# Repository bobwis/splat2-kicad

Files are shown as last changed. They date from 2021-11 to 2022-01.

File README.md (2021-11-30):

# splat2-kicad

Copy freerouter.jar to %appdata%\kicad  (needs java installation etc, not covered here)
Copy route.py to %appdata%\kicad\scripting\plugins  (create dir if doesn't exist)
Tools->External Plugins->Refresh

Preferences->Preferences->Pcbnew->Action Plugins
Select plugin
Click Show button

Now the hammer icon should be on the toolbar

To use
Export DSN to default file (do not rename)
Click the hammer

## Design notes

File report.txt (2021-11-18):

Info: Processing component “J15:/63877BF5:Connector_PinHeader_2.54mm:PinHeader_2x04_P2.54mm_Vertical”.

Info: Processing component “C4:/5BF5E583:Capacitor_SMD:C_1210_3225Metric_Pad1.42x2.65mm_HandSolder”.

Info: Processing component “R3:/5C0A226D:Capacitor_SMD:C_1210_3225Metric_Pad1.42x2.65mm_HandSolder”.

Info: Processing component “C23:/5BE7E7BD:Capacitor_THT:CP_Radial_D5.0mm_P2.50mm”.

Info: Processing component “C20:/6318842A:Capacitor_THT:CP_Radial_D5.0mm_P2.50mm”.

Info: Processing component “C5:/6216B77B:Capacitor_THT:CP_Radial_D5.0mm_P2.50mm”.

Info: Processing component “C2:/64F25216:Capacitor_THT:CP_Radial_D5.0mm_P2.50mm”.

Info: Processing component “J5:/5BD26EDD:Connector_Coaxial:SMA_Amphenol_132134-11_Vertical”.

Info: Processing component “J11:/63186258:Connector_PinHeader_2.54mm:PinHeader_1x02_P2.54mm_Vertical”.

Info: Processing component “J14:/61992824:Connector_PinHeader_2.54mm:PinHeader_1x02_P2.54mm_Vertical”.

Info: Processing component “J10:/62DA21AF:Connector_PinHeader_2.54mm:PinHeader_1x03_P2.54mm_Vertical”.

Info: Processing component “J9:/630317BA:Connector_PinHeader_2.54mm:PinHeader_1x03_P2.54mm_Vertical”.

Info: Processing component “J13:/62D151F9:Connector_PinHeader_2.54mm:PinHeader_1x04_P2.54mm_Vertical”.

Info: Processing component “C6:/5BDE9061:Capacitor_SMD:C_0805_2012Metric_Pad1.15x1.40mm_HandSolder”.

Info: Processing component “J1:/618B991A:Connector_Samtec_HLE_THT:Samtec_HLE-136-02-xx-DV-TE_2x36_P2.54mm_Horizontal”.

Info: Processing component “J2:/61D28094:Connector_Samtec_HLE_THT:Samtec_HLE-136-02-xx-DV-TE_2x36_P2.54mm_Horizontal”.

Info: Processing component “D1:/5BE6C923:Diode_SMD:D_SMA_Handsoldering”.

Info: Processing component “FB1:/61CAF7CB:Inductor_SMD:L_0805_2012Metric”.

Info: Processing component “FB2:/5BDA7EC0:Inductor_SMD:L_0805_2012Metric”.

Info: Processing component “FB3:/5BE721A5:Inductor_SMD:L_0805_2012Metric”.

Info: Processing component “FB4:/63597DFE:Inductor_SMD:L_0805_2012Metric”.

Info: Processing component “L1:/5BDE60A7:Inductor_SMD:L_1210_3225Metric_Pad1.42x2.65mm_HandSolder”.

Info: Processing component “L2:/5BDE8EA2:Inductor_SMD:L_1210_3225Metric_Pad1.42x2.65mm_HandSolder”.

Info: Processing component “D7:/5BF5D97C:LED_SMD:LED_PLCC-2”.

Info: Processing component “D2:/664D24EE:LED_SMD:LED_PLCC-2”.

Info: Processing component “C14:/63187970:Capacitor_SMD:C_0805_2012Metric”.

Info: Processing component “U3:/618C0BE9:SOIC127P790X216-8N”.

Info: Processing component “U4:/618C0AC4:SOIC127P790X216-8N”.

Info: Processing component “U6:/61E29CE2:XCVR_E180-ZG120A”.

Info: Processing component “C25:/631889B9:Capacitor_SMD:CP_Elec_8x10”.

Info: Processing component “C15:/5C4010D5:Capacitor_SMD:CP_Elec_8x10”.

Info: Processing component “C11:/635D681B:Capacitor_SMD:CP_Elec_8x10”.

Info: Processing component “C22:/635D69B8:Capacitor_SMD:C_0402_1005Metric”.

Info: Processing component “C18:/63188597:Capacitor_SMD:C_0402_1005Metric”.

Info: Processing component “C3:/5BDACAE4:Capacitor_SMD:C_0402_1005Metric”.

Info: Processing component “C26:/61B65493:Capacitor_SMD:C_0603_1608Metric”.

Info: Processing component “C16:/63187C64:Capacitor_SMD:C_0805_2012Metric”.

Info: Processing component “D8:/66EE6485:LED_SMD:LED_PLCC-2”.

Info: Processing component “C17:/63187D42:Capacitor_SMD:C_0805_2012Metric”.

Info: Processing component “C19:/63187E12:Capacitor_SMD:C_0805_2012Metric”.

Info: Processing component “C10:/6207CE49:Capacitor_SMD:C_0805_2012Metric”.

Info: Processing component “C21:/63187EDE:Capacitor_SMD:C_0805_2012Metric”.

Info: Processing component “C1:/65067AB3:Capacitor_SMD:C_0805_2012Metric”.

Info: Processing component “C8:/5C39DBA4:Capacitor_SMD:C_0805_2012Metric”.

Info: Processing component “C13:/5CCB7C4C:Capacitor_SMD:C_0805_2012Metric_Pad1.15x1.40mm_HandSolder”.

Info: Processing component “C12:/629B2DE5:Capacitor_SMD:C_0805_2012Metric_Pad1.15x1.40mm_HandSolder”.

Info: Processing component “C24:/62741EFC:Capacitor_SMD:C_0805_2012Metric_Pad1.15x1.40mm_HandSolder”.

Info: Processing component “C9:/62109AB0:Capacitor_SMD:C_0805_2012Metric_Pad1.15x1.40mm_HandSolder”.

Info: Processing component “C7:/5BDEBBA2:Capacitor_SMD:C_0805_2012Metric_Pad1.15x1.40mm_HandSolder”.

Info: Processing component “TP4:/5C0EA403:TestPoint:TestPoint_Loop_D1.80mm_Drill1.0mm_Beaded”.

Info: Processing component “RN2:/5BF93731:Resistor_SMD:R_Array_Convex_4x1206”.

Info: Processing component “RN1:/5BFA3139:Resistor_SMD:R_Array_Convex_4x1206”.

Info: Processing component “J17:/619A3715:TerminalBlock:TerminalBlock_Altech_AK300-2_P5.00mm”.

Info: Processing component “J16:/622C2AE8:TerminalBlock:TerminalBlock_Altech_AK300-3_P5.00mm”.

Info: Processing component “TP13:/5C43FB2E:TestPoint:TestPoint_Loop_D1.80mm_Drill1.0mm_Beaded”.

Info: Processing component “TP12:/5CAD6562:TestPoint:TestPoint_Loop_D1.80mm_Drill1.0mm_Beaded”.

Info: Processing component “TP11:/61EA61D7:TestPoint:TestPoint_Loop_D1.80mm_Drill1.0mm_Beaded”.

Info: Processing component “TP9:/61EE65FA:TestPoint:TestPoint_Loop_D1.80mm_Drill1.0mm_Beaded”.

Info: Processing component “TP7:/5C0DD6AD:TestPoint:TestPoint_Loop_D1.80mm_Drill1.0mm_Beaded”.

Info: Processing component “TP6:/62173C73:TestPoint:TestPoint_Loop_D1.80mm_Drill1.0mm_Beaded”.

Info: Processing component “TP5:/62DB8842:TestPoint:TestPoint_Loop_D1.80mm_Drill1.0mm_Beaded”.

Info: Processing component “R6:/5BF77C69:Resistor_SMD:R_2010_5025Metric_Pad1.52x2.65mm_HandSolder”.

Info: Processing component “TP3:/5C0EE9E7:TestPoint:TestPoint_Loop_D1.80mm_Drill1.0mm_Beaded”.

Info: Processing component “TP2:/5C399B72:TestPoint:TestPoint_Loop_D1.80mm_Drill1.0mm_Beaded”.

Info: Processing component “TP10:/6206B82B:TestPoint:TestPoint_Loop_D1.80mm_Drill1.0mm_Beaded”.

Info: Processing component “U2:/6186BFAC:spatboard:ESP-C3-13”.

Info: Processing component “U1:/5BD908A5:spatboard:NEO7_GPS_MODULE”.

Info: Processing component “J3:/61DA9D30:spatboard:PinHeader_1x04_P2.54mm_Vertical”.

Info: Processing component “J12:/657D39E5:spatboard:PinHeader_1x04_P2.54mm_Vertical”.

Info: Processing component “J8:/5BF652B8:spatboard:PinHeader_1x04_P2.54mm_Vertical”.

Info: Processing component “J7:/5BFC8F36:spatboard:PinHeader_1x04_P2.54mm_Vertical”.

Info: Processing component “J4:/620870AB:spatboard:PinHeader_1x04_P2.54mm_Vertical”.

Info: Processing component “U10:/61888ACD:spatboard:XCVR_E30-400M20S”.

Info: Processing component “R7:/6238E73C:Resistor_SMD:R_0805_2012Metric”.

Info: Processing component “D4:/5BF93B8D:LED_SMD:LED_PLCC-2”.

Info: Processing component “D3:/5C2D017B:LED_SMD:LED_PLCC-2”.

Info: Processing component “D5:/5BF5DD08:LED_SMD:LED_PLCC-2”.

Info: Processing component “D10:/5BFA313F:LED_SMD:LED_PLCC-2”.

Info: Processing component “D9:/5BFA312D:LED_SMD:LED_PLCC-2”.

Info: Processing component “D6:/5BF93B87:LED_SMD:LED_PLCC-2”.

Info: Processing component “U9:/61A5CBC2:Package_DFN_QFN:DFN-6-1EP_3x3mm_P1mm_EP1.5x2.4mm”.

Info: Processing component “U8:/5BD7F0EC:Package_SO:MSOP-10_3x3mm_P0.5mm”.

Info: Processing component “U5:/5BDA5FB8:Package_SO:SOIC-14_3.9x8.7mm_P1.27mm”.

Info: Processing component “Q1:/618490B7:Package_TO_SOT_SMD:SOT-23”.

Info: Processing component “U7:/6193E391:Package_TO_SOT_SMD:TO-252-3_TabPin2”.

Info: Processing component “J6:/6258932E:splatlib:3115_PRESSURE_MODULE”.

Info: Processing component “R8:/623D1A16:Resistor_SMD:R_0805_2012Metric”.

Info: Processing component “R1:/631C8D39:Resistor_SMD:R_0805_2012Metric”.

Info: Processing component “R9:/61BDFCA6:Resistor_SMD:R_0805_2012Metric”.

Info: Processing component “R2:/63DF97D8:Resistor_SMD:R_0805_2012Metric”.

Info: Processing component “R4:/664D24FB:Resistor_SMD:R_0805_2012Metric”.

Info: Processing component “R14:/66EE648E:Resistor_SMD:R_0805_2012Metric”.

Info: Processing component “R13:/618499ED:Resistor_SMD:R_0805_2012Metric”.

Info: Processing component “R11:/661F1C0A:Resistor_SMD:R_0805_2012Metric”.

Info: Processing component “R10:/61C1BE43:Resistor_SMD:R_0805_2012Metric”.

Info: Processing component “R12:/61849B7E:Resistor_SMD:R_0805_2012Metric”.

Info: Processing component “R5:/5BF77C6F:Resistor_SMD:R_2010_5025Metric_Pad1.52x2.65mm_HandSolder”.

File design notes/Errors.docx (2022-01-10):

SPLAT2 ERRORS

No annotation on Powerconn or 1 Wire

Pressure sensor INT2 connected to I2C_SDL PB9 (IOUT) – needs disconnecting on V1

LED Silkscreen is no help for polarity

Power arrangement review: 5V is live

Pad sizes on the 72 pin headers

Pad / hole sizes on GPS?

Best pad sizes for hybrids?

Op-Amp 10dB circuit is wrong – needs to float around half VPP

PG14 is connected to PE13 – PCB footprint is (probably) wrong for connector with two PE13s

PE13 is CS for ESP and also connects to PE4 SPI_NSS

Schematic PE5 MISO on 433MHz chip not quite connected

433MHz hybrid on upside down

Zigbee pin for config mode could be added PB11 on Zigbee, low=config, high =run

User Com7 PF6 label not global?

COM7 is now console

COM2 becomes user port

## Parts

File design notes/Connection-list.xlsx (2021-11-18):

CONN | PIN | SIGNAL NAME | STM FUNCTION APPLIED | USED FOR ON SPLAT2 | COMMENT
J1 | 1 | PC10 | SPI3_SCK | SPI FLASH AND NVRAM
J1 | 2 | PC11 | UART4_RX | E180 ZIGBEE PA0/TX
J1 | 3 | PC12 | UART5_TX | NEXTION RX
J1 | 4 | PD2 | SPARE | SPARE
J1 | 5 | VDD | External 3V3 supply from splat2 | Regulated 3V3 from 5V Regu;ator
J1 | 6 | E5V | External 5V | From offboard 5V Power Supply
J1 | 7 | BOOT0 | MAINBOARD Function | UNUSED
J1 | 8 | GND | GND | GND
J1 | 9 | PF6 | UART7_RX | USER COM7 (PC_TX)
J1 | 10 | NC |  | UNUSED
J1 | 11 | PF7 | UART7_TX | USER COM7 (PC_RX)
J1 | 12 | IOREF | ? | UNUSED
J1 | 13 | PA13 | TMS (debug serial wire) | UNUSED
J1 | 14 | NRST | ??? | UNUSED
J1 | 15 | PA14 | TCK (debug serial wire) | UNUSED
J1 | 16 | "+3V3 | power ??/ | UNUSED
J1 | 17 | PA15 | UART4_RTS | UNUSED
J1 | 18 | "+5V | power ??? | UNUSED
J1 | 19 | GND | GND | GND
J1 | 20 | GND | GND | GND
J1 | 21 | PB7 | BLUE LED LD2 ON STM MAINBOARD | UNUSED
J1 | 22 | GND | GND | GND
J1 | 23 | PC13 | USER BUTTON B1 | UNUSED
J1 | 24 | VIN | power ??? | UNUSED
J1 | 25 | PC14 | RCC_OSC32_IN | UNUSED
J1 | 26 | NC |  | UNUSED
J1 | 27 | PC15 | RCC_OSC32_OUT | UNUSED
J1 | 28 | PA0 | UART4_TX | E180 ZIGBEE PA1/RX
J1 | 29 | PH0 | MCO crystal | UNUSED
J1 | 30 | PA1 | LAN CLK | UNUSED
J1 | 31 | PH1 | RCC_OSC_OUT | UNUSED
J1 | 32 | PA4 | DAC_OUT | SPEAKER AMP ETC
J1 | 33 | VBAT | power / batt ??? | UNUSED
J1 | 34 | PB0 | LD1 (GREEN LED) Output | UNUSED
J1 | 35 | PC2 | SPI2_MISO | PGA AMP SPI SO
J1 | 36 | PC1 | LAN MDC | UNUSED
J1 | 37 | PC3 | SPI2_MISI | PGA AMP SPI SI
J1 | 38 | PC0 | UNUSED | UNUSED
J1 | 39 | PD4 | USART2_DE | UNUSED
J1 | 40 | PD3 | SPI2_SCK | PGA AMP SPI CLK
J1 | 41 | PD5 | USART2_TX | DEBUG COM2 CONN (TO PC RX)
J1 | 42 | PG2 | CS_PGA | PGA AMP /CS
J1 | 43 | PD6 | USART2_RX | DEBUG COM2 CONN (TO PC TX)
J1 | 44 | PG3 | UNUSED | E180 ZIGBEE TOUCH / PD13
J1 | 45 | PD7 | UNUSED | UNUSED
J1 | 46 | PE2 | SPI_SCK | PSI4_SCK On ESP32 and E30-433
J1 | 47 | PE3 | UNUSED | 48L512 RAM /HOLD
J1 | 48 | PE4 | SPI4_NSS | ESP32 FSPICS0 (WITH STM PE13)
J1 | 49 | GND | GND | GND
J1 | 50 | PE5 | SPI4_MISO | SPI4_MISO ESP32 and E30-433
J1 | 51 | PF1 | I2C2_SCL | USER I2C SCL
J1 | 52 | PF2 | UNUSED | E30-433 CTS
J1 | 53 | PF0 | I2C2_SDA | USER I2C DATA
J1 | 54 | PF8 | UART7_DE | UNUSED
J1 | 55 | PD1 | PROBE2 | PROBE2
J1 | 56 | PF9 | PROBE1 | PROBE1
J1 | 57 | PD0 | UNUSED | UNUSED
J1 | 58 | PG1 | UNUSED | UNUSED
J1 | 59 | PG0 | UNUSED | E180 ZIGBEE WAKE
J1 | 60 | GND | GND | GND
J1 | 61 | PE1 | UART6_TX | GPS RX DATA
J1 | 62 | PE6 | SPI4_MOSI | SPI_4_MOSI ESP32, E30-433
J1 | 63 | PG9 | USART6_RX | ESP32 TX DATA / GPIO21
J1 | 64 | PG15 | UART6_CTS | ESP32 RTS / GPIO9
J1 | 65 | PG12 | NC | ESP32 PF2 (General)
J1 | 66 | PG10 | NC | E180 ZIGBEE GPIO3 (General)
J1 | 67 | PH2 | ???? Dosesn't exist (variant) | UNUSED
J1 | 68 | PG13 | RMI TXDO ETH | UNUSED
J1 | 69 | PD9 | USART3_RX (Multiproc) | UNUSED
J1 | 70 | PG11 | RMI_TXEN | UNUSED
J1 | 71 | GND | GND | GND
J1 | 72 | GND | GND | GND
J2 | 1 | PC9 | UNUSED | PROBE3
J2 | 2 | PC8 | UNUSED | MPL3115A2 Module INT1
J2 | 3 | PB8 | TIM4_CH3 | TIMER OUTPUT FOR SPEAKER
J2 | 4 | PC6 | USART6_TX | ESP32 RXD(GPIO20)
J2 | 5 | PB9 | I2C1_SDA | SDA on 1-WIRE Controller
J2 | 6 | PC5 | RMI RXD1 (Eth) | UNUSED
J2 | 7 | AVDD | power ??? | UNUSED
J2 | 8 | U5V | power ??? | UNUSED
J2 | 9 | GND | GND | GND
J2 | 10 | PD8 | USART 3 STLK_RX (Multiproc) | UNUSED
J2 | 11 | PA5 | TIM2_CH1 | TIMEPULSE
J2 | 12 | PA12 | USB_OTG_FS_DP | UNUSED
J2 | 13 | PA6 | MDIOS_MDC | UNUSED
J2 | 14 | PA11 | USB_OTG_FS_DM | UNUSED
J2 | 15 | PA7 | ETH_CRS_DV | UNUSED
J2 | 16 | PB12 | UART5_RX | NEXTION TX
J2 | 17 | PB6 | I2C1_SCL | SCL on 1-WIRE Controller
J2 | 18 | PB11 | GPIO OUT | PROBE3
J2 | 19 | PC7 | TIM3_CH2 | UNUSED | 1 second timer
J2 | 20 | GND | GND | GND
J2 | 21 | PA9 | USB_VBUS | UNUSED
J2 | 22 | PB2 | SPI3_MOSI | SI ON FLASH AND NVRAM
J2 | 23 | PA8 | USB_OTG_FS_SOF | UNUSED
J2 | 24 | PB1 | UNUSED | IRQ ON E30-433
J2 | 25 | PB10 | TIM2_CH3 | TIMEPULSE
J2 | 26 | PB15 | UART4_CTS | E180 ZIGBEE PA3 US1_RTS | Leave floating
J2 | 27 | PB4 | SPI3_MISO | SO on FLASH AND NVRAM
J2 | 28 | PB14 | LD3 RED LED | UNUSED
J2 | 29 | PB5 | UNUSED | E30-433 SHUTDOWN
J2 | 30 | PB13 | RMII ETH TXD | UNUSED
J2 | 31 | PB3 | SWO SYS JTD0 | UNUSED
J2 | 32 | AGND | power ??? | AGND ON ANALOGUE RAIL
J2 | 33 | PA10 | MDIOS_MDIO | UNUSED
J2 | 34 | PC4 | RMII ETH RXD | UNUSED
J2 | 35 | PA2 | USART3_RX Multiproc | UNUSED
J2 | 36 | PF5 | UNUSED | UNUSED
J2 | 37 | PA3 | ADC1,2,3 IN | PGA ANALOGUE OUT TO STM ADC
J2 | 38 | PF4 | UNUSED | UNUSED
J2 | 39 | GND | GND | GND
J2 | 40 | PE8 | UNUSED | E180 ZIGBEE RESETN
J2 | 41 | PD13 | LED_D3 | LED_D4
J2 | 42 | PF10 | UNUSED | UNUSED
J2 | 43 | PD12 | LED_D2 | LED_D7
J2 | 44 | PE7 | UNUSED | RAM /CE
J2 | 45 | PD11 | LED_D1 | LED_D5
J2 | 46 | PD14 | LED_D4 | LED_D6
J2 | 47 | PE10 | XBEE_DTR | FLASH /HOLD
J2 | 48 | PD15 | LED_D5 | LED_D10
J2 | 49 | PE12 | GPIO_OUTPUT | PROBE6
J2 | 50 | PF14 | I2C4_SCL | UNUSED
J2 | 51 | PE14 | LP_FILT | FLASH / WP
J2 | 52 | PE9 | DAC_EXTI9 | UNUSED | dac interrupt input
J2 | 53 | PE15 | XBEE_RST | ESP32 ENABLE/RESET
J2 | 54 | GND | GND | GND
J2 | 55 | PE13 | UNUSED | SPI4_NSS / SPICS ESP32
J2 | 56 | PE11 | UNUSED | FLASH /CE
J2 | 57 | PF13 | UNUSED | PROBE5
J2 | 58 | PF3 | UNUSED | UNUSED
J2 | 59 | PF12 | UNUSED | PROBE4
J2 | 60 | PF15 | I2C4_SDA | UNUSED
J2 | 61 | PG14 | UNUSED | E30-433 /CS
J2 | 62 | PF11 | UNUSED | PROBE7
J2 | 63 | GND | GND | GND
J2 | 64 | PE0 | UART8_RX | GPS TXD
J2 | 65 | PD10 | UNUSED | UNUSED
J2 | 66 | PG8 | USART6_RTS | ESP32 CTS GPIO8
J2 | 67 | PG7 | USB OVERCURRENT | UNUSED
J2 | 68 | PG5 | UNUSED | E180 ZIGBEE LINK
J2 | 69 | PG4 | UNUSED | RE180 ZIGBEE AUX
J2 | 70 | PG6 | USB POWERSWITCHON | UNUSED
J2 | 71 | GND | GND | GND
J2 | 72 | GND | GND | GND

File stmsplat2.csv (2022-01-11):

Reference | Value | Footprint | Datasheet | DESC | DEC | Version | MANUFACTURER | Alternate | RS Components | MAXIMUM_PACKAGE_HEIGHT | PARTREV | STANDARD
U5 | Opamp_Quad_MCP6024 | Package_SO:SOIC-14_3.9x8.7mm_P1.27mm
FB2 | Ferrite_Bead | Inductor_SMD:L_0805_2012Metric | ~
C3 | 1uF | Capacitor_SMD:C_0805_2012Metric | ~
L1 | 620nH | Inductor_SMD:L_1210_3225Metric_Pad1.42x2.65mm_HandSolder | ~
L2 | 1.5uH | Inductor_SMD:L_1210_3225Metric_Pad1.42x2.65mm_HandSolder | ~
C6 | 560pF | Capacitor_SMD:C_0805_2012Metric_Pad1.15x1.40mm_HandSolder | ~
C7 | 240pF | Capacitor_SMD:C_0805_2012Metric_Pad1.15x1.40mm_HandSolder | ~
D1 | SMAJ8.0CA Bourns 9V | Diode_SMD:D_SMA_Handsoldering | http://www.farnell.com/datasheets/2076055.pdf
C23 | 10uF | Capacitor_SMD:CP_Elec_5x5.4 | ~
C4 | 47n | Capacitor_SMD:C_1210_3225Metric_Pad1.42x2.65mm_HandSolder | ~
J5 | Conn_Coaxial | Connector_Coaxial:SMA_Amphenol_132134-11_Vertical
TP7 | TestPoint | TestPoint:TestPoint_Loop_D1.80mm_Drill1.0mm_Beaded | ~
TP4 | TestPoint | TestPoint:TestPoint_Loop_D1.80mm_Drill1.0mm_Beaded | ~
TP3 | TestPoint | TestPoint:TestPoint_Loop_D1.80mm_Drill1.0mm_Beaded | ~
D7 | LED | LED_SMD:LED_PLCC-2 | ~
D5 | LED | LED_SMD:LED_PLCC-2 | ~
J8 | Conn_01x04_Male | PinHeader_1x04_P2.54mm_Vertical | ~ | NEXTION LCD
D6 | LED | LED_SMD:LED_PLCC-2 | ~
D4 | LED | LED_SMD:LED_PLCC-2 | ~
D10 | LED | LED_SMD:LED_PLCC-2 | ~
D9 | LED | LED_SMD:LED_PLCC-2 | ~ |  | 3V3GOOD
D3 | LED | LED_SMD:LED_PLCC-2 | ~
TP2 | TestPoint | TestPoint:TestPoint_Loop_D1.80mm_Drill1.0mm_Beaded | ~
TP13 | TestPoint | TestPoint:TestPoint_Loop_D1.80mm_Drill1.0mm_Beaded | ~
C8 | 4.7uF | Capacitor_SMD:C_0805_2012Metric | ~
TP12 | TestPoint | TestPoint:TestPoint_Loop_D1.80mm_Drill1.0mm_Beaded | ~
C13 | 470pF | Capacitor_SMD:C_0805_2012Metric_Pad1.15x1.40mm_HandSolder | ~
R6 | 100R | Resistor_SMD:R_0805_2012Metric | ~
R5 | 100R | Resistor_SMD:R_0805_2012Metric | ~
J7 | Conn_01x04_Male | PinHeader_1x04_P2.54mm_Vertical | ~ | DEBUG COM2
FB3 | Ferrite_Bead | Inductor_SMD:L_0805_2012Metric | ~
Q1 | BSS138LT1G | Package_TO_SOT_SMD:SOT-23 | ~
R13 | 100K | Resistor_SMD:R_0805_2012Metric | ~
R12 | 1K | Resistor_SMD:R_0805_2012Metric | ~
U9 | DS2485 | Package_DFN_QFN:DFN-6-1EP_3x3mm_P1mm_EP1.5x2.4mm
U2 | ESP-C3-13U | ESP-C3-13 | https://docs.ai-thinker.com/_media/esp32/docs/esp-c3-13_specification.pdf
J3 | Conn_01x04_Male | PinHeader_1x04_P2.54mm_Vertical | ~ | USB JTAG
U8 | MCP6S93-X_UN | Package_SO:MSOP-10_3x3mm_P0.5mm
R3 | 53R | Capacitor_SMD:C_1210_3225Metric_Pad1.42x2.65mm_HandSolder | ~
U10 | XCVR_E30-400M20S (Si4463) | splat2footprints:XCVR_E30-400M20S | https://www.aliexpress.com/item/1005003341113107.html |  |  | The module with the Si4463 (not Si4438) is prefered
U4 | 48L512-48LM01 | SOIC127P790X216-8N |  |  |  |  | Microchip
U3 | SST25VF032B | SOIC127P790X216-8N |  |  |  |  | Microchip | SST25VF016B (only 2MByte)
C5 | 100uF | Capacitor_SMD:CP_Elec_6.3x7.7 | ~
J10 | Conn_01x03_Male | Connector_PinHeader_2.54mm:PinHeader_1x03_P2.54mm_Vertical | ~
J1 | C11_2X36 | Connector_PinSocket_2.54mm:PinSocket_2x36_P2.54mm_Vertical | ~
J2 | C12_2X36 | Connector_PinSocket_2.54mm:PinSocket_2x36_P2.54mm_Vertical | ~
J4 | Conn_01x04_Male | PinHeader_1x04_P2.54mm_Vertical | ~ | DEBUG COM ESP
R1 | 4K7 | Resistor_SMD:R_0805_2012Metric | ~
U1 | ublox_chinese_PCB_module | NEO7_GPS_MODULE |  |  |  |  |  |  | M20-7890546
R2 | 3K3 | Resistor_SMD:R_0805_2012Metric | ~
C2 | 10uF | Capacitor_SMD:CP_Elec_5x5.4 | ~
C1 | 0.1uF | Capacitor_SMD:C_0805_2012Metric | ~
J12 | Conn_01x04_Male | PinHeader_1x04_P2.54mm_Vertical | ~ | JLINK
R11 | 470R | Resistor_SMD:R_0805_2012Metric | ~
D2 | LED | LED_SMD:LED_PLCC-2 | ~
R4 | 470R | Resistor_SMD:R_0805_2012Metric | ~
D8 | LED | LED_SMD:LED_PLCC-2 | ~
R14 | 470R | Resistor_SMD:R_0805_2012Metric | ~
R9 | 22K | Resistor_SMD:R_0805_2012Metric | ~
R10 | 10K | Resistor_SMD:R_0805_2012Metric | ~
U6 | E180-ZG120A | XCVR_E180-ZG120A |  |  |  |  | EBYTE |  |  | 2.55mm | 1.2 | Manufacturer Recommendations
TP11 | TestPoint | TestPoint:TestPoint_Loop_D1.80mm_Drill1.0mm_Beaded | ~
TP9 | TestPoint | TestPoint:TestPoint_Loop_D1.80mm_Drill1.0mm_Beaded | ~
TP10 | TestPoint | TestPoint:TestPoint_Loop_D1.80mm_Drill1.0mm_Beaded | ~
TP6 | TestPoint | TestPoint:TestPoint_Loop_D1.80mm_Drill1.0mm_Beaded | ~
R7 | 1K | Resistor_SMD:R_0805_2012Metric | ~
R8 | 1K | Resistor_SMD:R_0805_2012Metric | ~
C12 | 0.022uF | Capacitor_SMD:C_0805_2012Metric_Pad1.15x1.40mm_HandSolder | ~
J11 | Conn_01x02_Male | Connector_PinHeader_2.54mm:PinHeader_1x02_P2.54mm_Vertical | ~
C16 | 0.1uF | Capacitor_SMD:C_0805_2012Metric | ~
C17 | 0.1uF | Capacitor_SMD:C_0805_2012Metric | ~
C19 | 0.1uF | Capacitor_SMD:C_0805_2012Metric | ~
C21 | 0.1uF | Capacitor_SMD:C_0805_2012Metric | ~
C20 | 10uF | Capacitor_SMD:CP_Elec_5x5.4 | ~
C18 | 1uF | Capacitor_SMD:C_0805_2012Metric | ~
C11 | 100uF | Capacitor_SMD:CP_Elec_6.3x7.7 | ~
C22 | 1uF | Capacitor_SMD:C_0805_2012Metric | ~
FB1 | Ferrite_Bead | Inductor_SMD:L_0805_2012Metric | ~
C9 | 0.1uF | Capacitor_SMD:C_0805_2012Metric_Pad1.15x1.40mm_HandSolder | ~
J14 | Conn_01x02 | Connector_PinHeader_2.54mm:PinHeader_1x02_P2.54mm_Vertical | ~
J17 | Screw_Terminal_01x02 | TerminalBlock:TerminalBlock_Altech_AK300-2_P5.00mm | ~
C26 | 0.1uF | Capacitor_SMD:C_0805_2012Metric | ~
J16 | Screw_Terminal_01x03 | TerminalBlock:TerminalBlock_Altech_AK300-3_P5.00mm | ~
J13 | Conn_01x04_Male | Connector_PinHeader_2.54mm:PinHeader_1x04_P2.54mm_Vertical | ~ | USER COM7
J9 | Conn_01x03_Male | Connector_PinHeader_2.54mm:PinHeader_1x03_P2.54mm_Vertical | ~ | USER I2C
FB4 | Ferrite_Bead | Inductor_SMD:L_0805_2012Metric | ~
J15 | Conn_01x02 | Connector_PinHeader_2.54mm:PinHeader_2x04_P2.54mm_Vertical | ~
U11 | 3115_module | splat2footprints:3115_PRESSURE_MODULE | ~
J6 | Conn_01x04_Male | PinHeader_1x04_P2.54mm_Vertical | ~ | COMS BREAKOUT
R16 | 470R | Resistor_SMD:R_0805_2012Metric | ~
R17 | 470R | Resistor_SMD:R_0805_2012Metric | ~
R18 | 470R | Resistor_SMD:R_0805_2012Metric | ~
R19 | 470R | Resistor_SMD:R_0805_2012Metric | ~
R20 | 470R | Resistor_SMD:R_0805_2012Metric | ~
R15 | 470R | Resistor_SMD:R_0805_2012Metric | ~
R21 | 4K7 | Resistor_SMD:R_0805_2012Metric | ~
C27 | 0.1uF | Capacitor_SMD:C_0805_2012Metric_Pad1.15x1.40mm_HandSolder | ~
R22 | 4K7 | Resistor_SMD:R_0805_2012Metric | ~
C28 | 100uF | Capacitor_SMD:CP_Elec_6.3x7.7 | ~
R23 | 50R | Resistor_SMD:R_0805_2012Metric | ~
R24 | 33R | Resistor_SMD:R_0805_2012Metric | ~
R25 | 50R | Resistor_SMD:R_0805_2012Metric | ~
R26 | 110R | Resistor_SMD:R_0805_2012Metric | ~
C29 | 470pF | Capacitor_SMD:C_0805_2012Metric_Pad1.15x1.40mm_HandSolder | ~
C30 | 0.1uF | Capacitor_SMD:C_0805_2012Metric_Pad1.15x1.40mm_HandSolder | ~
C25 | 100uF | Capacitor_SMD:CP_Elec_6.3x7.7 | ~
C31 | 100uF | Capacitor_SMD:CP_Elec_6.3x7.7 | ~
SW1 | SW_DIP_x02 | Button_Switch_SMD:SW_DIP_SPSTx02_Slide_Omron_A6S-210x_W8.9mm_P2.54mm | ~
J18 | Conn_01x02_Male | Connector_PinHeader_2.54mm:PinHeader_1x02_P2.54mm_Vertical | ~
C14 | 0.1uF | Capacitor_SMD:C_0805_2012Metric | ~
J19 | Conn_01x02_Male | Connector_PinHeader_2.54mm:PinHeader_1x02_P2.54mm_Vertical | ~
U7 | AZ1084C | Package_TO_SOT_SMD:TO-252-3_TabPin2 | http://www.fairchildsemi.com/ds/LM/LM78M05.pdf
C15 | 100uF | Capacitor_SMD:CP_Elec_6.3x7.7 | ~
C24 | 10uF | Capacitor_SMD:CP_Elec_5x5.4 | ~
C10 | 0.1uF | Capacitor_SMD:C_0805_2012Metric | ~

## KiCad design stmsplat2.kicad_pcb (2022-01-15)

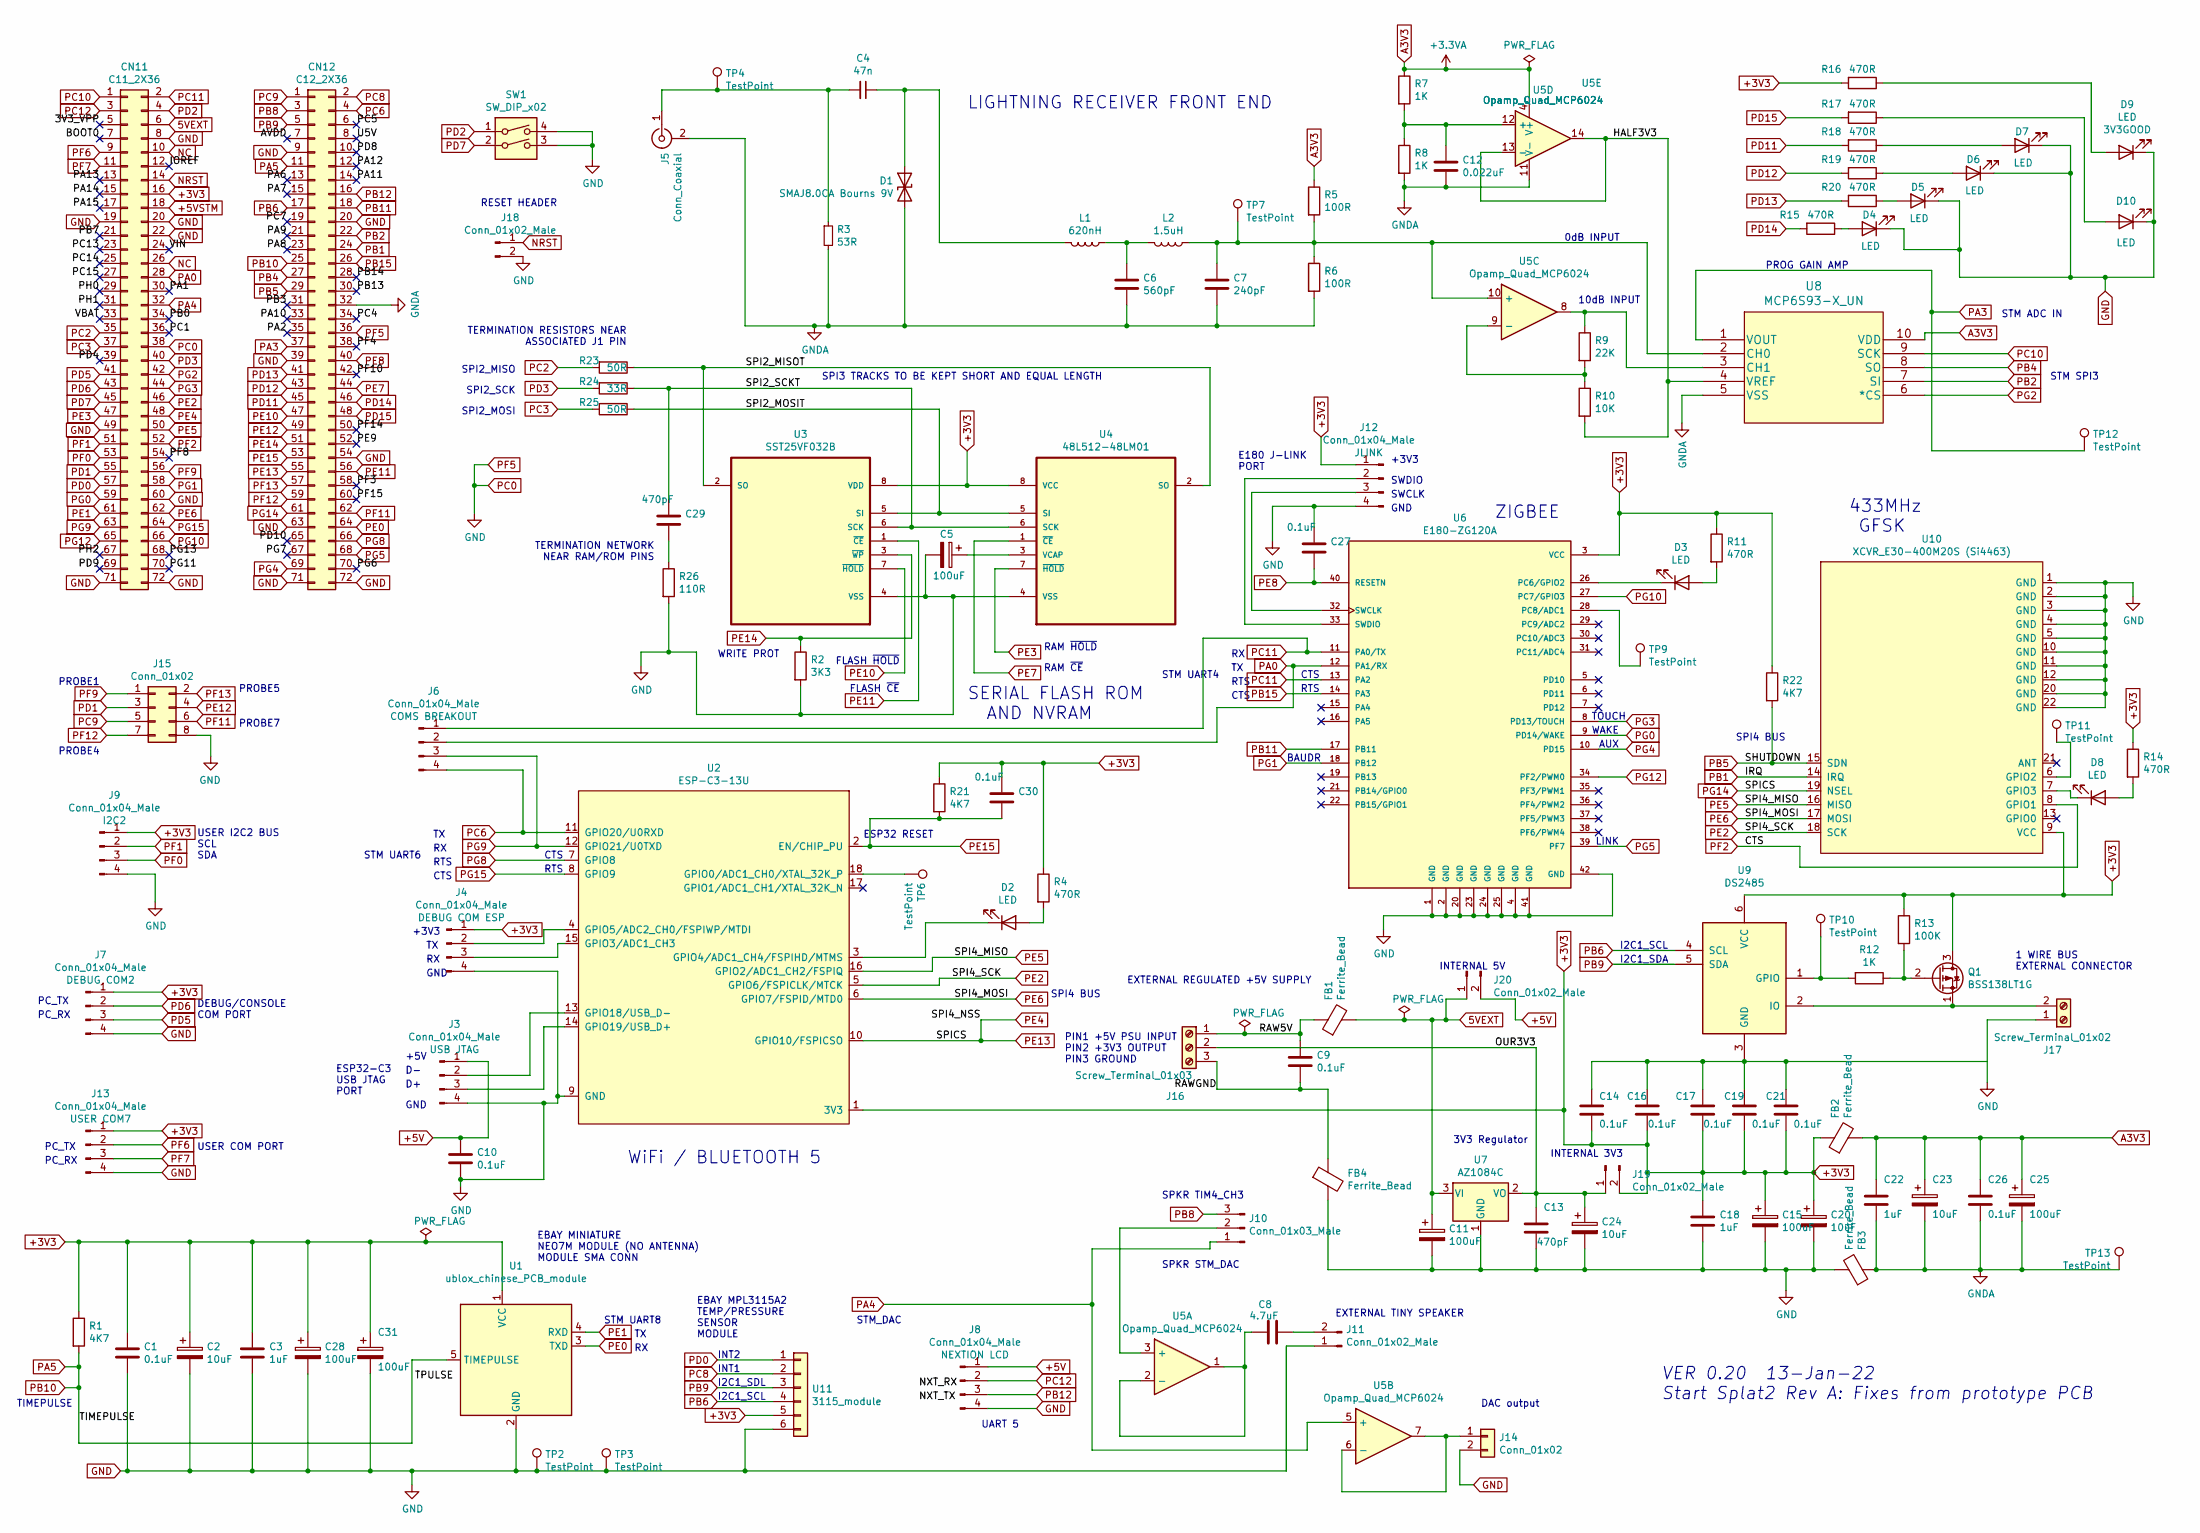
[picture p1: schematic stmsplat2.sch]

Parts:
C1, C10, C14, C16, C17, C19, C21, C26: 0.1uF; C_0805_2012Metric
C2, C20, C23, C24: 10uF; CP_Elec_5x5.4
C3, C18, C22: 1uF; C_0805_2012Metric
C4: 47n; C_1210_3225Metric_Pad1.42x2.65mm_HandSolder
C5, C11, C15, C25, C28, C31: 100uF; CP_Elec_6.3x7.7
C6: 560pF; C_0805_2012Metric_Pad1.15x1.40mm_HandSolder
C7: 240pF; C_0805_2012Metric_Pad1.15x1.40mm_HandSolder
C8: 4.7uF; C_0805_2012Metric
C9, C27, C30: 0.1uF; C_0805_2012Metric_Pad1.15x1.40mm_HandSolder
C12: 0.022uF; C_0805_2012Metric_Pad1.15x1.40mm_HandSolder
C13, C29: 470pF; C_0805_2012Metric_Pad1.15x1.40mm_HandSolder
CN11: C11_2X36; PinSocket_2x36_P2.54mm_Vertical
CN12: C12_2X36; PinSocket_2x36_P2.54mm_Vertical
D1: SMAJ8.0CA Bourns 9V; D_SMA_Handsoldering
D2, D3, D4, D5, D6, D7, D8, D9, D10: LED; LED_PLCC-2
FB1, FB2, FB3, FB4: Ferrite_Bead; L_0805_2012Metric
J3, J4, J6, J7, J8, J9, J12, J13: Conn_01x04_Male; PinHeader_1x04_P2.54mm_Vertical
J5: Conn_Coaxial; SMA_Amphenol_132134-11_Vertical
J10: Conn_01x03_Male; PinHeader_1x03_P2.54mm_Vertical
J11, J18, J19, J20: Conn_01x02_Male; PinHeader_1x02_P2.54mm_Vertical
J14: Conn_01x02; PinHeader_1x02_P2.54mm_Vertical
J15: Conn_01x02; PinHeader_2x04_P2.54mm_Vertical
J16: Screw_Terminal_01x03; TerminalBlock_Altech_AK300-3_P5.00mm
J17: Screw_Terminal_01x02; TerminalBlock_Altech_AK300-2_P5.00mm
L1: 620nH; L_1210_3225Metric_Pad1.42x2.65mm_HandSolder
L2: 1.5uH; L_1210_3225Metric_Pad1.42x2.65mm_HandSolder
Q1: BSS138LT1G; SOT-23
R1, R21, R22: 4K7; R_0805_2012Metric
R2: 3K3; R_0805_2012Metric
R3: 53R; C_1210_3225Metric_Pad1.42x2.65mm_HandSolder
R4, R11, R14, R15, R16, R17, R18, R19, R20: 470R; R_0805_2012Metric
R5, R6: 100R; R_0805_2012Metric
R7, R8, R12: 1K; R_0805_2012Metric
R9: 22K; R_0805_2012Metric
R10: 10K; R_0805_2012Metric
R13: 100K; R_0805_2012Metric
R23, R25: 50R; R_0805_2012Metric
R24: 33R; R_0805_2012Metric
R26: 110R; R_0805_2012Metric
SW1: SW_DIP_x02; SW_DIP_SPSTx02_Slide_Omron_A6S-210x_W8.9mm_P2.54mm
TP2, TP3, TP4, TP6, TP7, TP9, TP10, TP11, TP12, TP13: TestPoint; TestPoint_Loop_D1.80mm_Drill1.0mm_Beaded
U1: ublox_chinese_PCB_module; NEO7_GPS_MODULE
U2: ESP-C3-13U; ESP-C3-13
U3: SST25VF032B; SOIC127P790X216-8N
U4: 48L512-48LM01; SOIC127P790X216-8N
U5: Opamp_Quad_MCP6024; SOIC-14_3.9x8.7mm_P1.27mm
U6: E180-ZG120A; XCVR_E180-ZG120A; PARTREV 1.2
U7: AZ1084C; TO-252-3_TabPin2
U8: MCP6S93-X_UN; MSOP-10_3x3mm_P0.5mm
U9: DS2485; DFN-6-1EP_3x3mm_P1mm_EP1.5x2.4mm
U10: XCVR_E30-400M20S (Si4463); XCVR_E30-400M20S
U11: 3115_module; 3115_PRESSURE_MODULE

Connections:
5VEXT: C11.1, CN11.6, FB1.2, J20.1, U7.3 (VI)
+3V3: C1.1, C2.1, C3.1, C14.2, C15.1, C16.2, C17.2, C18.1, C19.2, C20.1, C21.2, C28.1, C30.1, C31.1, CN11.16, FB2.1, J4.1, J7.1, J9.1, J12.1, J13.1, J19.2, Q1.3 (D), R1.1, R4.1, R11.1, R13.1, R14.1, R16.2, R21.1, R22.1, U1.1 (VCC), U2.1 (3V3), U3.8 (VDD), U4.8 (VCC), U6.3 (VCC), U9.6 (VCC), U10.9 (VCC), U11.5
+5V: C10.1, J3.1, J8.1, J20.2
+5VSTM: CN11.18
/3V3_VPP: CN11.5
/AVDD: CN12.7
/BOOT0: CN11.7
/HALF3V3: R10.2, U5.13 (-), U5.14, U8.4 (VREF)
/IOREF: CN11.12
/OUR3V3: C13.1, C24.1, J16.2, J19.1, U7.2 (VO)
/PA1: CN11.30
/PA2: CN12.35
/PA6: CN12.13
/PA7: CN12.15
/PA8: CN12.23
/PA9: CN12.21
/PA10: CN12.33
/PA11: CN12.14
/PA12: CN12.12
/PA13: CN11.13
/PA14: CN11.15
/PA15: CN11.17
/PB0: CN11.34
/PB3: CN12.31
/PB7: CN11.21
/PB13: CN12.30
/PB14: CN12.28
/PC1: CN11.36
/PC4: CN12.34
/PC5: CN12.6
/PC7: CN12.19
/PC13: CN11.23
/PC14: CN11.25
/PC15: CN11.27
/PD4: CN11.39
/PD8: CN12.10
/PD9: CN11.69
/PD10: CN12.65
/PE9: CN12.52
/PF3: CN12.58
/PF4: CN12.38
/PF8: CN11.54
/PF10: CN12.42
/PF14: CN12.50
/PF15: CN12.60
/PG6: CN12.70
/PG7: CN12.67
/PG11: CN11.70
/PG13: CN11.68
/PH0: CN11.29
/PH1: CN11.31
/PH2: CN11.67
/RAW5V: C9.1, FB1.1, J16.1
/RAWGND: C9.2, FB4.1, J16.3
/SPI2_MISOT: R23.1, U3.2 (SO), U4.2 (SO)
/SPI2_MOSIT: R25.1, U3.5 (SI), U4.5 (SI)
/SPI2_SCKT: C29.1, R24.1, U3.6 (SCK), U4.6 (SCK)
/U5V: CN12.8
/VBAT: CN11.33
/VIN: CN11.24
A3V3: C22.1, C23.1, C25.1, C26.1, FB2.2, R5.1, R7.1, U5.4 (V+), U8.10 (VDD)
GNDA: C6.2, C7.2, C12.2, C22.2, C23.2, C25.2, C26.2, CN12.32, D1.2 (A2), FB3.1, J5.2 (Ext), R3.2, R6.2, R8.2, TP13.1, U5.11 (V-), U8.5 (VSS); also elsewhere on the board
NC: CN11.10, CN11.26
NRST: CN11.14, J18.1
unnamed: C4.1, D1.1 (A1), L1.2
unnamed: C4.2, J5.1 (In), R3.1, TP4.1
unnamed: C5.1, U4.3 (VCAP)
unnamed: C6.1, L1.1, L2.2
unnamed: C7.1, L2.1, R5.2, R6.1, TP7.1, U5.10 (+), U8.2 (CH0)
unnamed: C8.1, U5.1, U5.2 (-)
unnamed: C8.2, J11.2
unnamed: C12.1, R7.2, R8.1, U5.12 (+)
unnamed: C29.2, R26.1
unnamed: D2.1 (K), U2.3 (GPIO4/ADC1_CH4/FSPIHD/MTMS)
unnamed: D2.2 (A), R4.2
unnamed: D3.1 (K), U6.26 (PC6/GPIO2)
unnamed: D3.2 (A), R11.2
unnamed: D4.2 (A), R15.1
unnamed: D5.2 (A), R20.1
unnamed: D6.2 (A), R19.1
unnamed: D7.2 (A), R18.1
unnamed: D8.1 (K), U10.7 (GPIO3)
unnamed: D8.2 (A), R14.2
unnamed: D9.2 (A), R16.1
unnamed: D10.2 (A), R17.1
unnamed: J3.2, U2.13 (GPIO18/USB_D-)
unnamed: J3.3, U2.14 (GPIO19/USB_D+)
unnamed: J4.2, U2.4 (GPIO5/ADC2_CH0/FSPIWP/MTDI)
unnamed: J4.3, U2.15 (GPIO3/ADC1_CH3)
unnamed: J10.2, U5.3 (+)
unnamed: J12.2, U6.33 (SWDIO)
unnamed: J12.3, U6.32 (SWCLK)
unnamed: J14.1, U5.6 (-), U5.7
unnamed: J17.2, Q1.1 (S), U9.2 (IO)
unnamed: Q1.2 (G), R12.1, R13.2
unnamed: R9.1, U5.8, U8.3 (CH1)
unnamed: R9.2, R10.1, U5.9 (-)
unnamed: R12.2, TP10.1, U9.1 (GPIO)
unnamed: TP6.1, U2.18 (GPIO0/ADC1_CH0/XTAL_32K_P)
unnamed: TP9.1, U6.28 (PC8/ADC1)
unnamed: TP11.1, U10.6 (GPIO2)
PA0: CN11.28, J6.2, U6.12 (PA1/RX)
PA3: CN12.37, TP12.1, U8.1 (VOUT)
PA4: CN11.32, J10.1, U5.5 (+)
PA5: CN12.11, CN12.25, R1.2, U1.5 (TIMEPULSE)
PB1: CN12.24, U10.14 (IRQ)
PB2: CN12.22, U8.7 (SI)
PB4: CN12.27, U8.8 (SO)
PB5: CN12.29, R22.2, U10.15 (SDN)
PB6: CN12.17, U9.4 (SCL), U11.4
PB8: CN12.3, J10.3
PB9: CN12.5, U9.5 (SDA), U11.3
PB11: CN12.18, U6.17 (PB11)
PB12: CN12.16, J8.3
PB15: CN12.26, U6.14 (PA3)
PC2: CN11.35, R23.2
PC3: CN11.37, R25.2
PC6: CN12.4, J6.4, U2.11 (GPIO20/U0RXD)
PC8: CN12.2, U11.2
PC9: CN12.1, J15.5
PC10: CN11.1, U8.9 (SCK)
PC11: CN11.2, J6.1, U6.11 (PA0/TX), U6.13 (PA2)
PC12: CN11.3, J8.2
PD0: CN11.57, U11.1
PD1: CN11.55, J15.3
PD2: CN11.4, SW1.1
PD3: CN11.40, R24.2
PD5: CN11.41, J7.3
PD6: CN11.43, J7.2
PD7: CN11.45, SW1.2
PD11: CN12.45, R18.2
PD12: CN12.43, R19.2
PD13: CN12.41, R20.2
PD14: CN12.46, R15.2
PD15: CN12.48, R17.2
PE0: CN12.64, U1.3 (TXD)
PE1: CN11.61, U1.4 (RXD)
PE2: CN11.46, U2.5 (GPIO6/FSPICLK/MTCK), U10.18 (SCK)
PE3: CN11.47, U4.7 (~HOLD)
PE5: CN11.50, U2.16 (GPIO2/ADC1_CH2/FSPIQ), U10.16 (MISO)
PE6: CN11.62, U2.6 (GPIO7/FSPID/MTD0), U10.17 (MOSI)
PE7: CN12.44, U4.1 (~CE)
PE8: C27.2, CN12.40, U6.40 (RESETN)
PE10: CN12.47, U3.7 (~HOLD)
PE11: CN12.56, U3.1 (~CE)
PE12: CN12.49, J15.4
PE13: CN11.48, CN12.55, CN12.61, U2.10 (GPIO10/FSPICSO), U10.19 (NSEL)
PE14: CN12.51, R2.1, U3.3 (~WP)
PE15: C30.2, CN12.53, R21.2, U2.2 (EN/CHIP_PU)
PF0: CN11.53, J9.3
PF1: CN11.51, J9.2
PF2: CN11.52, U10.8 (GPIO1)
PF6: CN11.9, J13.2
PF7: CN11.11, J13.3
PF9: CN11.56, J15.1
PF11: CN12.62, J15.6
PF12: CN12.59, J15.7
PF13: CN12.57, J15.2
PG0: CN11.59, U6.9 (PD14/WAKE)
PG1: CN11.58, U6.18 (PB12)
PG2: CN11.42, U8.6 (*CS)
PG3: CN11.44, U6.8 (PD13/TOUCH)
PG4: CN12.69, U6.10 (PD15)
PG5: CN12.68, U6.39 (PF7)
PG8: CN12.66, U2.7 (GPIO8)
PG9: CN11.63, J6.3, U2.12 (GPIO21/U0TXD)
PG10: CN11.66, U6.27 (PC7/GPIO3)
PG12: CN11.65, U6.34 (PF2/PWM0)
PG15: CN11.64, U2.8 (GPIO9)

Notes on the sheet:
STM UART8
I2C1_SCL
I2C1_SDA
RTS
CTS
ESP32 RESET
1 WIRE BUS EXTERNAL CONNECTOR
DAC output
EBAY MPL3115A2 TEMP/PRESSURE SENSOR MODULE
I2C1_SDL
UART 5
ESP32-C3 USB JTAG PORT
SPI2_SCK
SPI2_MOSI
SPI2_MISO
SPI3 TRACKS TO BE KEPT SHORT AND EQUAL LENGTH
STM_DAC
SPKR TIM4_CH3
SPKR STM_DAC
SPI4 BUS
STM UART6
PC_RX
PC_TX
+3V3
GND
TIMEPULSE
+5V
RAM ~HOLD
RAM ~CE
FLASH ~CE
FLASH ~HOLD
STM UART4
E180 J-LINK PORT
SWDIO
SWCLK
RTS
BAUDR
AUX
WAKE
TOUCH

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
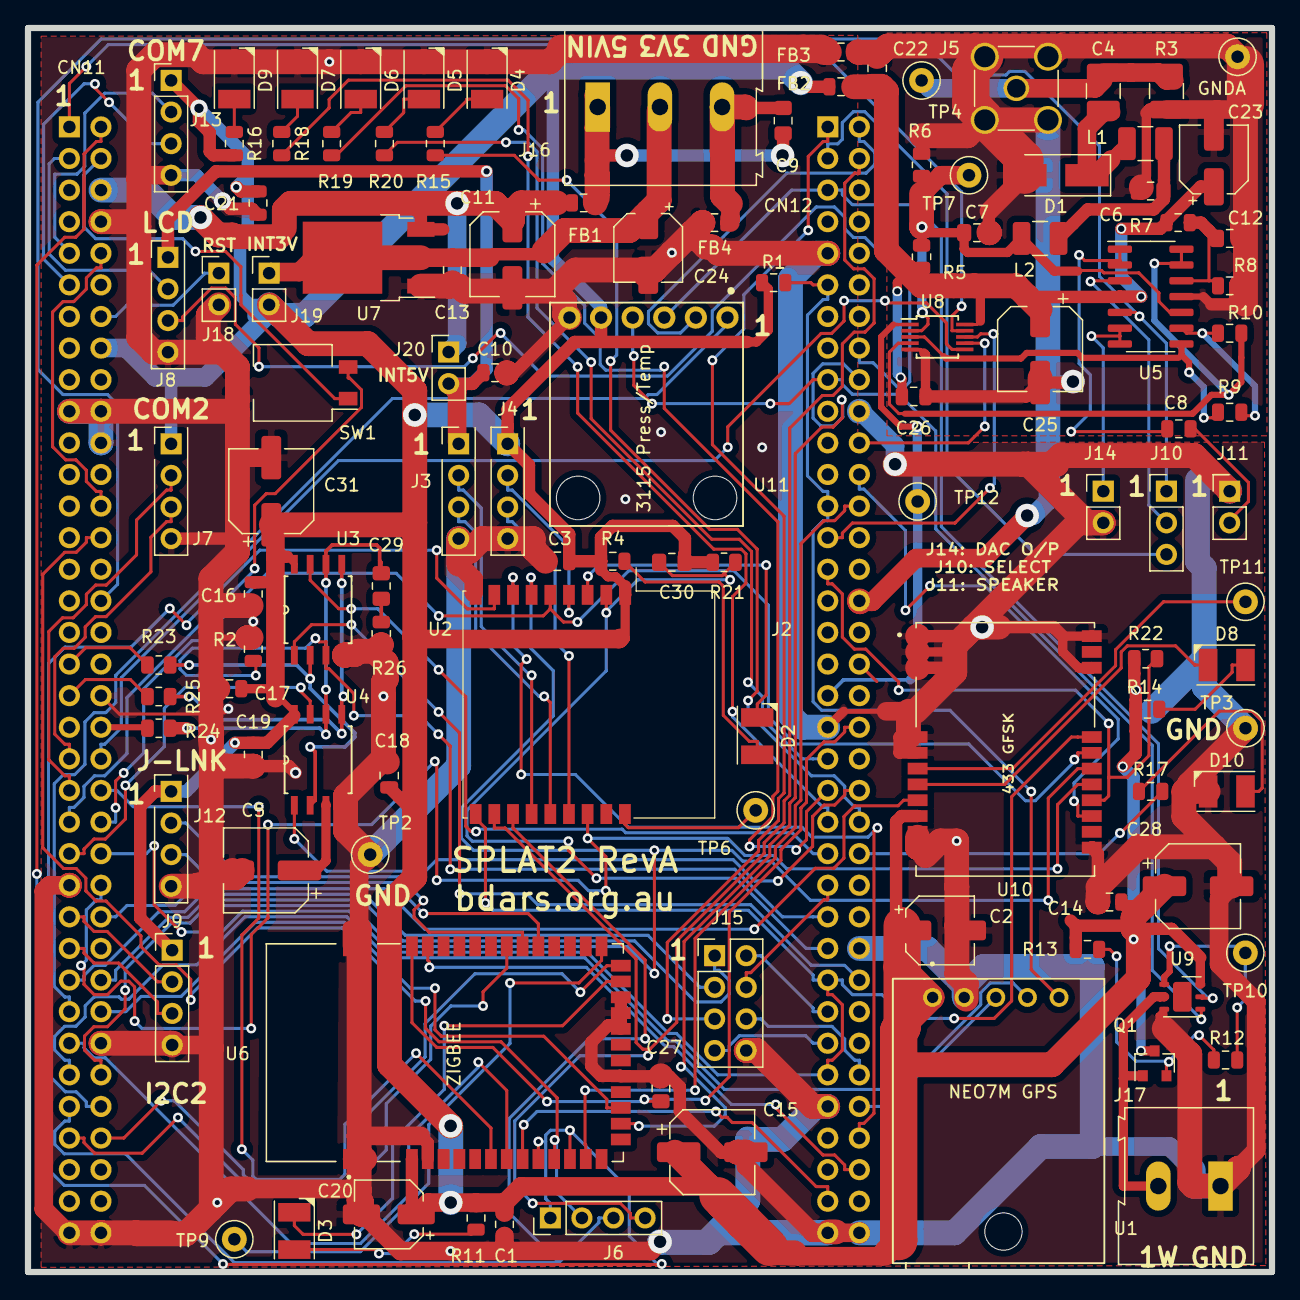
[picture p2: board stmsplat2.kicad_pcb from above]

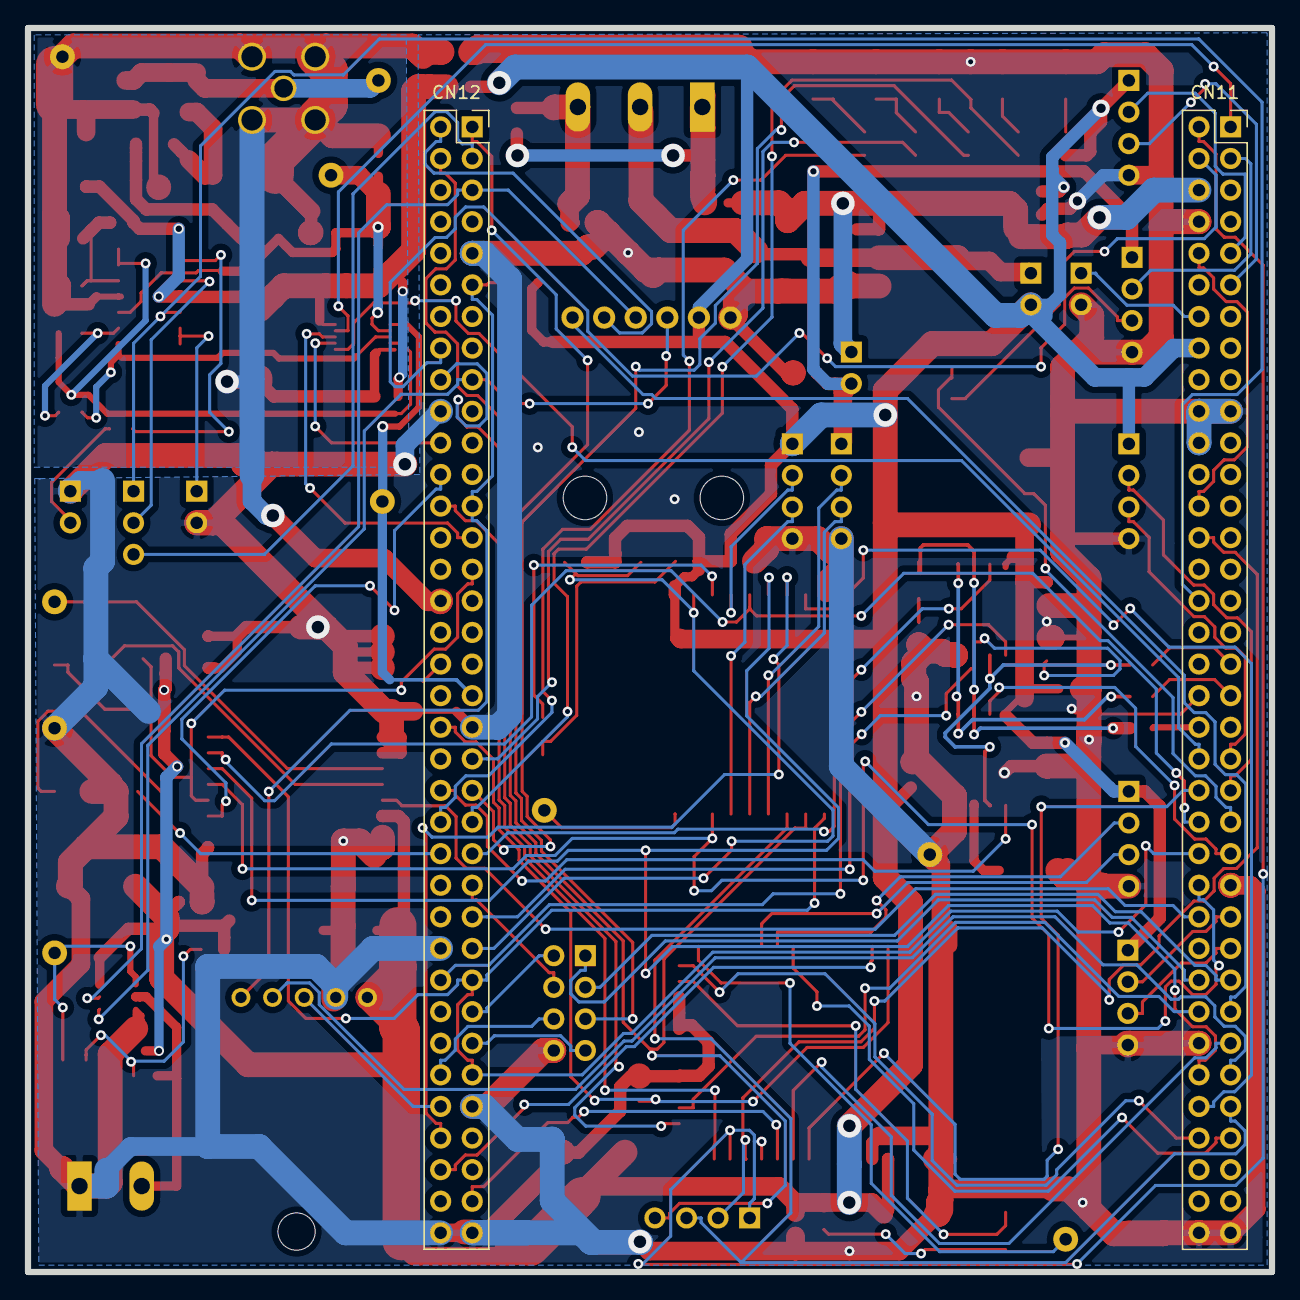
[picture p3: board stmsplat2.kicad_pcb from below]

Board: 2 copper layers, 100.0 x 100.0 mm, 116 parts (2 on the bottom side), 120 nets.

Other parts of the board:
GNDA: TestPoint; TestPoint_Loop_D1.80mm_Drill1.0mm_Beaded

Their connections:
GNDA: GNDA.1; also elsewhere on the board

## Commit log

2021-11-17 Added kicad files
    [stmsplat2.kicad_pcb, stmsplat2.sch]
2021-11-18 Connector mods
    Changed power rails to work with onboard/offboard 5V supply
    Added user header for GPIO signals / Probes
    Added User UART and I2C header
    checked 72 pin connectors and signal names to devices
    **STILL NEEDS ERC and FOOTPRINT updates *** After Supply sourcing checks
    [Connection-list.xlsx]
2021-11-18 changed all 0603 footprints to 0805 in the schematic
    [stmsplat2.csv, stmsplat2.kicad_pcb, stmsplat2.sch]
2021-11-18 forgot to bump Sch ver to 0.04
    [stmsplat2.sch]
2021-11-18 deleted old splat1 pcb outline
    [stmsplat2.kicad_pcb]
2021-11-23 ERC check resolution, resolved empty / unused nets
    [stmsplat2.sch]
2021-11-23 0 ERC - modified custom lib to clarify pin types
    [stmsplat2.sch]
2021-11-23 Rejigged library
    [stmsplat2.sch]
2021-11-24 Corrected typo
    [stmsplat2.sch]
2021-11-24 Removed references to spatboard
    [stmsplat2.sch]
2021-11-24 Removed more spatboard references
    [stmsplat2.kicad_pcb]
2021-11-24 Footprints to new format and all link to the custom splat2footprints library
    VER 0.07: ALMOST FROZEN - pretty library footprints,
    3115 footprint unfinished and
    changed from J to U designation on SCH
    Added com breakout header
    labeled raw5v and rawgnd
2021-11-24 updated 3115 module footprint and on the PCB
    [stmsplat2.kicad_pcb]
2021-11-24 Thrown down the components and made a 100x100 outline to see how well it might fit
    [_saved_stmsplat2.sch, stmsplat2.kicad_pcb]
2021-11-26 Ver 0.9. Initial PCB placement attempt. Some footprints changed
    [stmsplat2.kicad_pcb, stmsplat2.sch]
2021-11-26 Spectra Export
    [stmsplat2.dsn]
2021-11-26 improved placement]
    [stmsplat2.dsn, stmsplat2.kicad_pcb]
2021-11-27 Added a few passives in sch. Library update may not be good? Placement tweaks.
    [stmsplat2.dsn, stmsplat2.kicad_pcb, stmsplat2.sch]
2021-11-27 updated DSN
    [stmsplat2.dsn]
2021-11-28 Few footprints changes, placement changes, initial routing success
    SCH: 0.11 (now feature frozen)
    PCB: Placement 1.2
    PCB Routed 1.0
    The unrouted pcb is also in this folder
    [stmsplat2.dsn, stmsplat2.sch, stmsplat2_unrouted.kicad_pcb]
2021-11-28 I think this is the correct .dsn file used to generate the last PCB?
    [stmsplat2.dsn]
2021-11-29 SPI2<->SPI3. Different placement. Routed, but may have other errors
    Swapped SPI2 and SPI3 and have added termination for SPI2 (which may not be needed)/ Moved RAM/ROM components close to the connector
    [stmsplat2-p1.kicad_pcb, stmsplat2.dsn, stmsplat2.kicad_pcb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]
2021-11-29 added BOM and removed old pcb
    [stmsplat2-p1.kicad_pcb]
2021-11-29 Routing attempt
    [stmsplat2_unrouted.dsn, stmsplat2_unrouted.kicad_pcb]
2021-11-30 placement candidate 2 with routed candidate 1.0
    [stmsplat2-p1.kicad_pcb, stmsplat2.sch, stmsplat2_autorouted.kicad_pcb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]
2021-12-01 better placement, more handrouting, re-done power area etc
    A few more passive comps added including dil switch
    [stmsplat2.dsn, stmsplat2.kicad_pcb, stmsplat2.sch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]
2021-12-04 PCB Layout finished. Gerbers produced, needs checking
    Ready to send off to PCB house?
    [stmsplat2-B_Cu.gbr, stmsplat2-B_Mask.gbr, stmsplat2-Edge_Cuts.gbr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]
2021-12-06 U8 pads adjustment. PC0->GND, minor silkscreen tweaks
    [stmsplat2-B_Cu.gbr, stmsplat2-B_Mask.gbr, stmsplat2-Dwgs_User.gbr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]
2021-12-06 more silkscreen tweaks
    [stmsplat2-B_Cu.gbr, stmsplat2-B_Mask.gbr, stmsplat2-Dwgs_User.gbr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]
2021-12-07 Updated bom
2021-12-20 Correct the PowerConn Pin assignments
    these were changed to facilitate easier PCB layout
    [stmsplat2.sch]
2021-12-20 Forgot to bump Schematic version
    This is now bumped to Ver 0.18
    [stmsplat2.sch]
2022-01-10 Splat2 Revision A. Work-in-progress
    [stmsplat2.dsn, stmsplat2.kicad_pcb, stmsplat2.sch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]
2022-01-11 Routed but needs checking
    [stmsplat2.csv, stmsplat2.dsn, stmsplat2.kicad_pcb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]
2022-01-11 Copper pours added
    [stmsplat2.kicad_pcb]
2022-01-15 Sent off for PCB manufacture
    [stmsplat2.kicad_pcb, stmsplat2.sch, stmsplat2_unrouted.dsn]
